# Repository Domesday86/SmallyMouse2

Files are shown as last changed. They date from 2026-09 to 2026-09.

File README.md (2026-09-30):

## Synopsis

SmallyMouse2 is the AT90USB1287 firmware source code and KiCAD schematic/PCB design for the SmallyMouse2 project.

Detailed documentation is available on the [SmallyMouse2 wiki](https://github.com/domesday86/SmallyMouse2/wiki).

The schematic and PCB design in `KiCAD/` are in the KiCad 10 file format and require KiCad 10 or later to open. The original KiCad 4 files are available in the git history (commit `66cf90d` and earlier).

## Motivation

SmallyMouse2 is a project that creates a USB mouse adaptor for retro computers that use quadrature mouse input including the Acorn BBC Micro, Acorn Master series, Commodore Amiga, Atari ST, busmouse compatible computers and many more.  SmallyMouse2 provides both a generic mouse output header (for attaching mouse to retro computer cables) and an IDC connector suitable for use with Acorn 8-bit user-ports.  SmallyMouse2 also features a configurable quadrature rate limiter that prevents VIA overrun when in use with slower 8-bit machines.

SmallyMouse2 supports both JTAG and USB bootloader programming.  The AT90USB1287 is pre-programmed by Atmel with the (FLIP) DFU bootloader; this bootloader is recognised by Atmel Studio as a programming device and can be used to flash the firmware to the board.

## Installation

The firmware is built with the open-source AVR GNU toolchain (avr-gcc, avr-binutils, avr-libc) and CMake. A Nix flake supplies the complete, pinned toolchain along with the programming tools (avrdude for the Atmel-ICE, dfu-programmer for the USB bootloader).

### Building

Enter the firmware development shell (`code`, also the default) and build out-of-tree using a CMake preset:

    nix develop                     # or: nix develop .#code
    cmake --preset release          # or: cmake --preset debug
    cmake --build --preset release

The output is written to `build/release/`:

| File | Use |
|---|---|
| `SmallyMouse2.hex`  | Flash image (Intel HEX) - JTAG via avrdude, DFU via dfu-programmer  |
| `SmallyMouse2-with-bootloader.hex` | Firmware merged with the LUFA DFU bootloader - JTAG via avrdude |
| `SmallyMouse2.elf`  | Full image with symbols - JTAG via Microchip Studio / debugging |
| `SmallyMouse2.eep`  | EEPROM image (currently empty) |
| `SmallyMouse2.srec` | Flash image (Motorola S-record) |
| `SmallyMouse2.lss`  | Extended listing |
| `SmallyMouse2.map`  | Linker map |

Alternatively `nix build` produces the same files in `./result/` without entering a shell.

Without Nix, any avr-gcc toolchain, CMake 3.24+ and Ninja on the `PATH` will work with the same commands.

### Programming via JTAG (Atmel-ICE)

Connect the Atmel-ICE to the JTAG header, then:

    cmake --build --preset release --target flash-jtag

or, without a build tree, `nix run .#flash-jtag`. The fuses and lock bits can be read with the `read-fuses-jtag` target.

Programming over JTAG performs a chip erase, which also removes the DFU bootloader, so `flash-jtag` writes `SmallyMouse2-with-bootloader.hex` (the firmware merged with the LUFA DFU bootloader) and the board can still be updated over USB afterwards. The bootloader image comes from the Nix flake; without it (`BOOTLOADER_HEX` unset) `flash-jtag` writes the firmware alone and the bootloader is lost.

### Restoring the DFU bootloader and fuses (Atmel-ICE)

If the bootloader is missing (for example after programming with another tool) or the fuses no longer select it, connect the Atmel-ICE and run:

    nix run .#flash-bootloader-jtag

or, from the dev shell, `cmake --build --preset release --target flash-bootloader-jtag`. This builds the LUFA DFU bootloader from the pinned LUFA source, erases the chip, writes the bootloader and sets the high/extended fuses to the factory values (`hfuse 0x99`, `efuse 0xF3`: 8 KB boot section, JTAG enabled, HWB bootloader entry enabled). The LUFA bootloader uses the same USB ID as the factory one, so the DFU steps below work unchanged. Any application firmware is removed; reprogram it over USB afterwards.

### Programming via USB (DFU bootloader)

Put the AT90USB1287 into its factory DFU bootloader (hold HWB low while resetting), then:

    cmake --build --preset release --target flash-dfu

or `nix run .#flash-dfu`. The device is erased, programmed and then started.

### USB permissions (udev)

On Linux, programming as a normal user needs udev rules for two devices:

| Device | USB ID | Used by |
|---|---|---|
| Atmel-ICE | `03eb:2141` | avrdude |
| AT90USB1287 DFU bootloader | `03eb:2ffb` | dfu-programmer |

The Atmel-ICE needs two rules. avrdude can reach it through libusb or through hidapi, and each uses a different device node (`usb` and `hidraw`).

On NixOS, add the rules to your system configuration:

```nix
services.udev.extraRules = ''
  # Atmel-ICE (AVR JTAG programmer) - usb node for libusb, hidraw node for hidapi
  SUBSYSTEM=="usb", ATTRS{idVendor}=="03eb", ATTRS{idProduct}=="2141", MODE="660", GROUP="users"
  SUBSYSTEM=="hidraw", ATTRS{idVendor}=="03eb", ATTRS{idProduct}=="2141", MODE="660", GROUP="users"
  # AT90USB1287 DFU bootloader
  SUBSYSTEM=="usb", ATTRS{idVendor}=="03eb", ATTRS{idProduct}=="2ffb", MODE="660", GROUP="users"
'';
```

On other distributions, put the same three lines in a file such as `/etc/udev/rules.d/70-smallymouse2.rules`. Make sure your user is in the group the rules name, or change `GROUP` to one it is in (for example `plugdev` on Debian and Ubuntu). Then reload the rules with `sudo udevadm control --reload-rules`.

On either system, unplug and replug the device after adding the rules.

## Case

`Case/` holds an OpenSCAD case design, built with the [BOSL2](https://github.com/BelfrySCAD/BOSL2) library:

| File | Contents |
|---|---|
| `pcb.scad`  | Dimensional model of the assembled board, built from the footprint placements in `KiCAD/SmallyMouse2.kicad_pcb`, with helpers giving the board-space position of any part by reference (for example `pcb_part_box("P1")` for the USB connector) |
| `case.scad` | Two-part case (base and lid) positioned against the board model |

### Opening the design

From the repository root, enter the `openscad` dev shell and open the case:

    nix develop .#openscad
    openscad Case/case.scad

Start OpenSCAD from inside the dev shell: the shell sets `OPENSCADPATH` to the pinned BOSL2, so `include <BOSL2/std.scad>` fails if OpenSCAD is started any other way (for example from the desktop menu). `openscad Case/pcb.scad` opens the board model on its own.

Open the Customizer (Window → Customizer) and set `part` to choose what is shown:

| `part` | Shows |
|---|---|
| `assembly` | Base, board and a transparent lid together; raise `explode` to lift the lid |
| `base` | The base alone, laid out for printing |
| `lid` | The lid alone, turned over for printing |
| `pcb` | The board alone |

The case dimensions (wall thickness, clearances, standoff height and so on) are in the same panel.

F5 gives a fast preview; F6 does the full render needed before exporting an STL with F7.

### Exporting STLs

Without the GUI, `nix build .#case` renders `case-base.stl`, `case-lid.stl` and `case-pcb.stl` into `./result/`. A single part can be exported from the dev shell with, for example:

    openscad -o case-lid.stl -D 'part="lid"' Case/case.scad

Component heights that are not in the KiCad data (the USB connector, IDC header and pin headers) use typical datasheet values, set near the top of `pcb.scad`; check them against the parts fitted before printing.

## Author

SmallyMouse2 is written and maintained by Simon Inns.

## License (Software)

    SmallyMouse2 is free software: you can redistribute it and/or modify
    it under the terms of the GNU General Public License as published by
    the Free Software Foundation, either version 3 of the License, or
    (at your option) any later version.

    SmallyMouse2 is distributed in the hope that it will be useful,
    but WITHOUT ANY WARRANTY; without even the implied warranty of
    MERCHANTABILITY or FITNESS FOR A PARTICULAR PURPOSE.  See the
    GNU General Public License for more details.

    You should have received a copy of the GNU General Public License
    along with SmallyMouse2. If not, see <http://www.gnu.org/licenses/>.

## License (Hardware)

Both the schematic and the PCB design of SmallyMouse2 (i.e. the KiCAD project and files) are covered by a Creative Commons license; as with the software you are welcome (and encouraged!) to extend, re-spin and otherwise use and modify the design as allowed by the license.  However; under the terms of the Attribution-ShareAlike 4.0 International (CC BY-SA 4.0) license you are required to release your design (or redesign) under the same license.  For details of the licensing requirements please see <https://creativecommons.org/licenses/by-sa/4.0/>

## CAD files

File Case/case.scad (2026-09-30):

// SmallyMouse2 case
//
// A two-part case: a base tray that the board sits in on four standoffs, and
// a lid that closes over it. Both parts split at the top face of the PCB, so
// the USB connector drops into a slot in the lid wall. Four M3 screws go up
// through the base, standoffs and board into pilot holes in the lid pillars,
// clamping everything together.
//
// The case is modelled in the board coordinates of pcb.scad (origin at the
// centre of the board, Z = 0 on its bottom face), so case features can be
// placed directly from the PCB model's measurements. The output is then
// lifted so the base sits on Z = 0, keeping the Z axis through the centre of
// the board.
//
// Set `part` to choose what is rendered; from the command line:
//   openscad -o case-base.stl -D 'part="base"' case.scad

PCB_LIBRARY_ONLY = true;
include <pcb.scad>

part = "assembly";  // [assembly, base, lid, pcb]
explode = 0;        // Lift the lid in the assembly view

/* [Case] */
wall = 2.0;
floor_thickness = 2.0;
top_thickness = 2.0;
corner_radius = 3.0;
board_gap = 0.5;        // Clearance around the board edge
opening_gap = 0.5;      // Clearance around connectors through the lid
usb_gap = 0.3;          // Clearance around the USB shell in the lid slot
usb_protrusion = 0.5;   // USB mouth stands proud of the case wall

/* [Fixings] */
standoff_height = 4.0;  // Must clear PCB_PIN_TAIL
standoff_d = 8.5;       // Must be wider than screw_head_d
pillar_d = 5.5;         // Must fit in PCB_HOLE_KEEPOUT_D
screw_clearance_d = 3.4;
screw_pilot_d = 2.5;    // M3 self-tapping into plastic
screw_head_d = 6.0;
screw_head_depth = 3.0;

/* [Lid openings] */
// J1 expansion header
open_j1 = true;
// J2 slow/fast jumper
open_j2 = true;
// J3 BBC Micro user port (IDC)
open_j3 = true;
// J4 universal output header
open_j4 = true;
// J5 bootloader jumper
open_j5 = true;
// J6 reset jumper
open_j6 = true;
// Gap above a covered connector; the lid is raised to suit
lid_clearance = 1.0;

/* [Hidden] */
// Connectors under the lid, and whether each has an opening
LID_CONNECTORS = [
    ["J1", open_j1],
    ["J2", open_j2],
    ["J3", open_j3],
    ["J4", open_j4],
    ["J5", open_j5],
    ["J6", open_j6],
];
LID_OPENINGS = [for (c = LID_CONNECTORS) if (c[1]) c[0]];
LID_COVERED = [for (c = LID_CONNECTORS) if (!c[1]) c[0]];

// ---------------------------------------------------------------------------
// Derived dimensions (board coordinates)

usb_box = pcb_part_box("P1");

case_min = [usb_box[0].x + usb_protrusion, -PCB_SIZE.y / 2 - board_gap - wall];
case_max = PCB_SIZE / 2 + [board_gap + wall, board_gap + wall];
inner_min = case_min + [wall, wall];
inner_max = case_max - [wall, wall];

z_bottom = -standoff_height - floor_thickness;
z_split = PCB_THICKNESS;
// The lid underside clears the USB shell and any covered connector; the IDC
// shroud, when it has an opening, reaches the lid's top
z_top = max([
    pcb_part_top("P1") + usb_gap + top_thickness,
    if (open_j3) pcb_part_top("J3"),
    for (ref = LID_COVERED) pcb_part_top(ref) + lid_clearance + top_thickness,
]);
z_ceiling = z_top - top_thickness;

assert(standoff_height > PCB_PIN_TAIL, "Standoffs too short for the pin tails");
assert(standoff_d >= screw_head_d + 2, "Standoffs too thin around the screw head recess");
assert(pillar_d <= PCB_HOLE_KEEPOUT_D, "Lid pillars overlap the hole keep-out");

echo(str("Case outside: ", case_max - case_min, " x ", z_top - z_bottom, " mm"));
echo(str("Screw: M3 x ", floor(z_ceiling - z_bottom - screw_head_depth - 1), " mm or shorter"));

// ---------------------------------------------------------------------------

// Rounded box between two XY corners, from z0 to z1.
module rounded_box(p0, p1, z0, z1, r) {
    translate([(p0.x + p1.x) / 2, (p0.y + p1.y) / 2, z0])
        cuboid([p1.x - p0.x, p1.y - p0.y, z1 - z0], rounding = r, edges = "Z",
               anchor = BOT);
}

module shell(z0, z1) {
    difference() {
        rounded_box(case_min, case_max, z0, z1, corner_radius);
        rounded_box(inner_min, inner_max, z0 - 1, z1 + 1, corner_radius - wall);
    }
}

module base() {
    difference() {
        union() {
            shell(z_bottom, z_split);
            rounded_box(case_min, case_max, z_bottom, z_bottom + floor_thickness,
                        corner_radius);
            for (h = PCB_HOLES) translate(h)
                cyl(d = standoff_d, h = standoff_height, anchor = TOP);
        }
        for (h = PCB_HOLES) translate(h) {
            cyl(d = screw_clearance_d, h = 50);
            translate([0, 0, z_bottom - 1])
                cyl(d = screw_head_d, h = screw_head_depth + 1, anchor = BOT);
        }
    }
}

// Screw pillars from the lid's underside down to the top of the board.
module lid_pillars() {
    for (h = PCB_HOLES) translate([h.x, h.y, PCB_THICKNESS])
        cyl(d = pillar_d, h = z_ceiling - PCB_THICKNESS, anchor = BOT);
}

// Blind pilot holes for the screws
module lid_pilot_holes() {
    for (h = PCB_HOLES) translate([h.x, h.y, PCB_THICKNESS - 1])
        cyl(d = screw_pilot_d, h = z_top - PCB_THICKNESS, anchor = BOT);
}

module lid() {
    difference() {
        union() {
            shell(z_split, z_top);
            rounded_box(case_min, case_max, z_ceiling, z_top, corner_radius);
            lid_pillars();
        }
        lid_pilot_holes();
        // USB slot, open at the bottom of the lid wall
        translate([0, 0, z_split - 1])
            cube_between([case_min.x - 1, usb_box[0].y - usb_gap],
                         [inner_min.x + 1, usb_box[1].y + usb_gap],
                         pcb_part_top("P1") + usb_gap - z_split + 1);
        for (ref = LID_OPENINGS) let (b = pcb_part_box(ref))
            translate([0, 0, z_ceiling - 1])
                cube_between(b[0] - [opening_gap, opening_gap],
                             b[1] + [opening_gap, opening_gap], top_thickness + 2);
    }
}

// Square-edged block between two XY corners, from z = 0 to z = h.
module cube_between(p0, p1, h) {
    translate([p0.x, p0.y, 0]) cube([p1.x - p0.x, p1.y - p0.y, h]);
}

// Lifts from board coordinates to the output frame, with the underside of
// the base on Z = 0.
module on_bed() {
    translate([0, 0, -z_bottom]) children();
}

if (part == "assembly") {
    on_bed() {
        color("#606060") base();
        smallymouse2_pcb();
        translate([0, 0, explode]) {
            // The preview (F5) hides whatever is drawn after a transparent
            // part, including the lid's own pillars, so they are drawn again
            // as solid parts before the lid
            if ($preview) color("SteelBlue") difference() {
                lid_pillars();
                lid_pilot_holes();
            }
            color("SteelBlue", 0.5) lid();
        }
    }
} else if (part == "base") {
    on_bed() base();
} else if (part == "lid") {
    // Top down on the print bed
    translate([0, 0, z_top - z_bottom]) xrot(180) on_bed() lid();
} else if (part == "pcb") {
    // Where it sits in the assembly, so it lines up with the base
    on_bed() smallymouse2_pcb();
}

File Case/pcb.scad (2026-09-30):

// SmallyMouse2 PCB model for case design
//
// A dimensional model of the assembled SmallyMouse2 board, built from the
// footprint placements in KiCAD/SmallyMouse2.kicad_pcb. It is meant for
// measuring a case against, not as a photorealistic render: component bodies
// are simple blocks at their nominal (datasheet-typical) sizes.
//
// Board coordinates (used by everything in this file and by case.scad):
//   origin  - centre of the board outline, on the bottom face of the PCB
//   X       - right, along the 52.3 mm edge
//   Y       - up the board, as seen in KiCad's top view
//   Z       - up from the bottom face; the top (component) face is at
//             PCB_THICKNESS
//
// Footprints are described in their own KiCad-local coordinates (Y down),
// so the numbers below can be checked directly against the .kicad_pcb and
// the footprints in KiCAD/SmallyMouse2.pretty.
//
// Open this file on its own to view the board. case.scad includes it as a
// library by setting PCB_LIBRARY_ONLY first.

include <BOSL2/std.scad>

$fa = 4;
$fs = 0.25;

// ---------------------------------------------------------------------------
// Board

// Edge.Cuts rectangle: (120.904, 80.264) - (173.228, 122.428) in KiCad
PCB_KICAD_ORIGIN = [147.066, 101.346];  // KiCad position of the board centre
PCB_SIZE = [52.324, 42.164];
PCB_THICKNESS = 1.6;

// M3 mounting holes (MK1-MK4). The keep-out is the ISO 14580 screw head
// courtyard on the top side.
PCB_HOLE_D = 3.2;
PCB_HOLE_KEEPOUT_D = 6.0;

// Through-hole pins stand proud of the bottom face by this much (2.54 mm
// headers: 3.0 mm tail below the plastic, less the board thickness). Leave at
// least this under the board.
PCB_PIN_TAIL = 3.0 - PCB_THICKNESS;

// ---------------------------------------------------------------------------
// Component sizes that are not in the KiCad data. These come from typical
// datasheet values; check against the parts actually fitted.

USB_A_HEIGHT = 7.0;         // Amphenol 87583-2010BLF shell height above board
IDC_HEIGHT = 8.9;           // 2x10 boxed (shrouded) header
HEADER_BODY_HEIGHT = 2.5;   // 2.54 mm pin header plastic
HEADER_PIN_HEIGHT = 8.5;    // 2.54 mm pin header, pin tip above board
TQFP_HEIGHT = 1.2;
XTAL_HEIGHT = 1.2;
C0805_HEIGHT = 0.85;
R0805_HEIGHT = 0.5;

// ---------------------------------------------------------------------------
// Footprint placements, from the .kicad_pcb:
//   [reference, type, KiCad position, KiCad rotation, pin count]

PCB_PARTS = [
    ["C1",  "C0805",  [132.334, 109.474],  90],
    ["C2",  "C0805",  [135.128, 109.474],  90],
    ["C3",  "C0805",  [141.478,  89.662], 180],
    ["C4",  "C0805",  [135.128, 100.076],  90],
    ["C5",  "C0805",  [136.652,  89.662], 180],
    ["C6",  "C0805",  [141.224, 110.998], 180],
    ["C7",  "C0805",  [149.352,  89.408],   0],
    ["C8",  "C0805",  [151.892, 115.062],   0],
    ["C9",  "C0805",  [163.830, 119.888], 180],
    ["C10", "C0805",  [161.290,  83.058],   0],
    ["R1",  "R0805",  [133.350,  96.774], 180],
    ["R2",  "R0805",  [133.350,  94.742], 180],
    ["R3",  "R0805",  [153.924, 111.252], -90],
    ["R4",  "R0805",  [126.365,  89.408], -90],
    ["IC1", "TQFP64", [145.288, 100.076],   0],
    ["Y1",  "XTAL",   [134.874, 114.046], 180],
    ["P1",  "USB_A",  [126.492, 101.346], -90],
    ["J1",  "HEADER", [130.302, 118.872],  90, 10],  // Expansion header
    ["J2",  "HEADER", [153.162,  86.614], 180,  2],  // Slow/Fast jumper
    ["J3",  "IDC20",  [162.306, 113.030],  90],      // BBC Micro user port
    ["J4",  "HEADER", [168.656, 113.030], 180, 10],  // Universal output
    ["J5",  "HEADER", [131.826, 104.648],  90,  2],  // Bootloader jumper
    ["J6",  "HEADER", [129.413,  90.170], 180,  2],  // Reset jumper
    ["TP1", "TP",     [132.080,  83.820],   0],      // JTAG test points
    ["TP2", "TP",     [137.668,  83.820],   0],
    ["TP3", "TP",     [143.256,  83.820],   0],
    ["TP4", "TP",     [146.050,  83.820], 180],
    ["TP5", "TP",     [134.874,  83.820], 180],
    ["TP6", "TP",     [140.462,  83.820], 180],
    ["TP7", "TP",     [148.844,  83.820],   0],
];

PCB_MOUNTING_HOLES_KICAD = [
    [124.460,  83.820],  // MK1
    [124.460, 118.618],  // MK2
    [169.672,  83.820],  // MK3
    [169.672, 118.618],  // MK4
];

// ---------------------------------------------------------------------------
// Coordinate conversion

// KiCad board position -> board coordinates
function kicad_xy(p) = [p.x - PCB_KICAD_ORIGIN.x, PCB_KICAD_ORIGIN.y - p.y];

// Footprint-local point -> board coordinates. KiCad's local Y points down and
// its rotation is counter-clockwise as seen from the top, so flipping Y turns
// it into an ordinary OpenSCAD rotation.
function fp_xy(at, rot, p) =
    let (c = cos(rot), s = sin(rot), q = [p.x, -p.y])
    kicad_xy(at) + [c * q.x - s * q.y, s * q.x + c * q.y];

// Places children, modelled in footprint-local coordinates with Z = 0 on the
// board's top face, onto the board.
module footprint(at, rot) {
    translate([each kicad_xy(at), PCB_THICKNESS]) zrot(rot) yflip() children();
}

PCB_HOLES = [for (h = PCB_MOUNTING_HOLES_KICAD) kicad_xy(h)];

// ---------------------------------------------------------------------------
// Part lookup, for positioning case features

function pcb_part(ref) = [for (p = PCB_PARTS) if (p[0] == ref) p][0];

// Local-coordinate outline [[x0, y0], [x1, y1]] and height above the board
// of each footprint type.
function part_outline(part) =
    let (type = part[1], pins = part[4])
      type == "C0805"  ? [[-1.0, -0.625], [1.0, 0.625]]
    : type == "R0805"  ? [[-1.0, -0.625], [1.0, 0.625]]
    : type == "TQFP64" ? [[-8, -8], [8, 8]]
    : type == "XTAL"   ? [[-2.5, -1.6], [2.5, 1.6]]
    : type == "USB_A"  ? [[-6.57, -1.07], [6.57, 12.84]]
    : type == "IDC20"  ? [[-5.08, -5.82], [27.94, 3.28]]
    : type == "HEADER" ? [[-1.27, -1.27], [1.27, (pins - 0.5) * 2.54]]
    : type == "TP"     ? [[-0.75, -0.75], [0.75, 0.75]]
    : assert(false, str("Unknown footprint type ", type));

function part_height(part) =
    let (type = part[1])
      type == "C0805"  ? C0805_HEIGHT
    : type == "R0805"  ? R0805_HEIGHT
    : type == "TQFP64" ? TQFP_HEIGHT
    : type == "XTAL"   ? XTAL_HEIGHT
    : type == "USB_A"  ? USB_A_HEIGHT
    : type == "IDC20"  ? IDC_HEIGHT
    : type == "HEADER" ? HEADER_PIN_HEIGHT
    : type == "TP"     ? 0.05
    : assert(false, str("Unknown footprint type ", type));

// Board-coordinate bounding box [[x0, y0], [x1, y1]] of a part, e.g.
// pcb_part_box("P1") for the USB connector (its mouth is the -X face).
function pcb_part_box(ref) =
    let (
        part = pcb_part(ref),
        o = part_outline(part),
        pts = [for (x = [o[0].x, o[1].x], y = [o[0].y, o[1].y])
                   fp_xy(part[2], part[3], [x, y])]
    )
    [[min([for (p = pts) p.x]), min([for (p = pts) p.y])],
     [max([for (p = pts) p.x]), max([for (p = pts) p.y])]];

// Height of a part's top above the bottom face of the board.
function pcb_part_top(ref) = PCB_THICKNESS + part_height(pcb_part(ref));

// Tallest part, above the bottom face of the board.
PCB_TOP = max([for (p = PCB_PARTS) PCB_THICKNESS + part_height(p)]);

// ---------------------------------------------------------------------------
// Model

PCB_COLOUR = "#1f6b2d";
COPPER_COLOUR = "gold";
METAL_COLOUR = "silver";
PLASTIC_COLOUR = "#202020";

// Box between two local-coordinate corners, from z0 to z1.
module _box(p0, p1, z0, z1) {
    translate([(p0.x + p1.x) / 2, (p0.y + p1.y) / 2, z0])
        cuboid([abs(p1.x - p0.x), abs(p1.y - p0.y), z1 - z0], anchor = BOT);
}

module _chip(height, body_colour) {
    color(body_colour) _box([-0.75, -0.625], [0.75, 0.625], 0, height);
    color(METAL_COLOUR)
        for (x = [-1, 1]) _box([x * 0.75, -0.625], [x * 1.0, 0.625], 0, height);
}

module _tqfp64() {
    color(PLASTIC_COLOUR) difference() {
        _box([-7, -7], [7, 7], 0.1, TQFP_HEIGHT);
        // Pin 1 marker
        translate([-5.5, -5.5, TQFP_HEIGHT]) cyl(d = 1, h = 0.2);
    }
    color(METAL_COLOUR)
        for (side = [0 : 3], i = [0 : 15])
            zrot(side * 90) translate([7.5, (i - 7.5) * 0.8, 0])
                cuboid([1, 0.37, 0.15], anchor = BOT);
}

module _xtal() {
    color("#c8b88a") _box([-2.5, -1.6], [2.5, 1.6], 0, 0.3);
    color(METAL_COLOUR) _box([-2.3, -1.4], [2.3, 1.4], 0.3, XTAL_HEIGHT);
}

// Amphenol 87583-2010BLF USB-A receptacle; the mouth faces local +Y.
module _usb_a() {
    color(METAL_COLOUR) difference() {
        _box([-6.57, -1.07], [6.57, 12.84], 0, USB_A_HEIGHT);
        _box([-6.0, 2.84], [6.0, 12.94], 1.0, USB_A_HEIGHT - 1.0);
    }
    color("white") _box([-5.6, 2.84], [5.6, 11.84], 3.4, 5.2);
    // Board-locating shell pegs through the 2.3 mm holes
    color(METAL_COLOUR)
        for (x = [-6.57, 6.57]) translate([x, 2.14, 0])
            cyl(d = 2.0, h = PCB_THICKNESS + 1, anchor = TOP);
    color(METAL_COLOUR)
        for (x = [-3.5, -1, 1, 3.5]) _box([x - 0.3, -2.5], [x + 0.3, -1.07], 0, 0.2);
}
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

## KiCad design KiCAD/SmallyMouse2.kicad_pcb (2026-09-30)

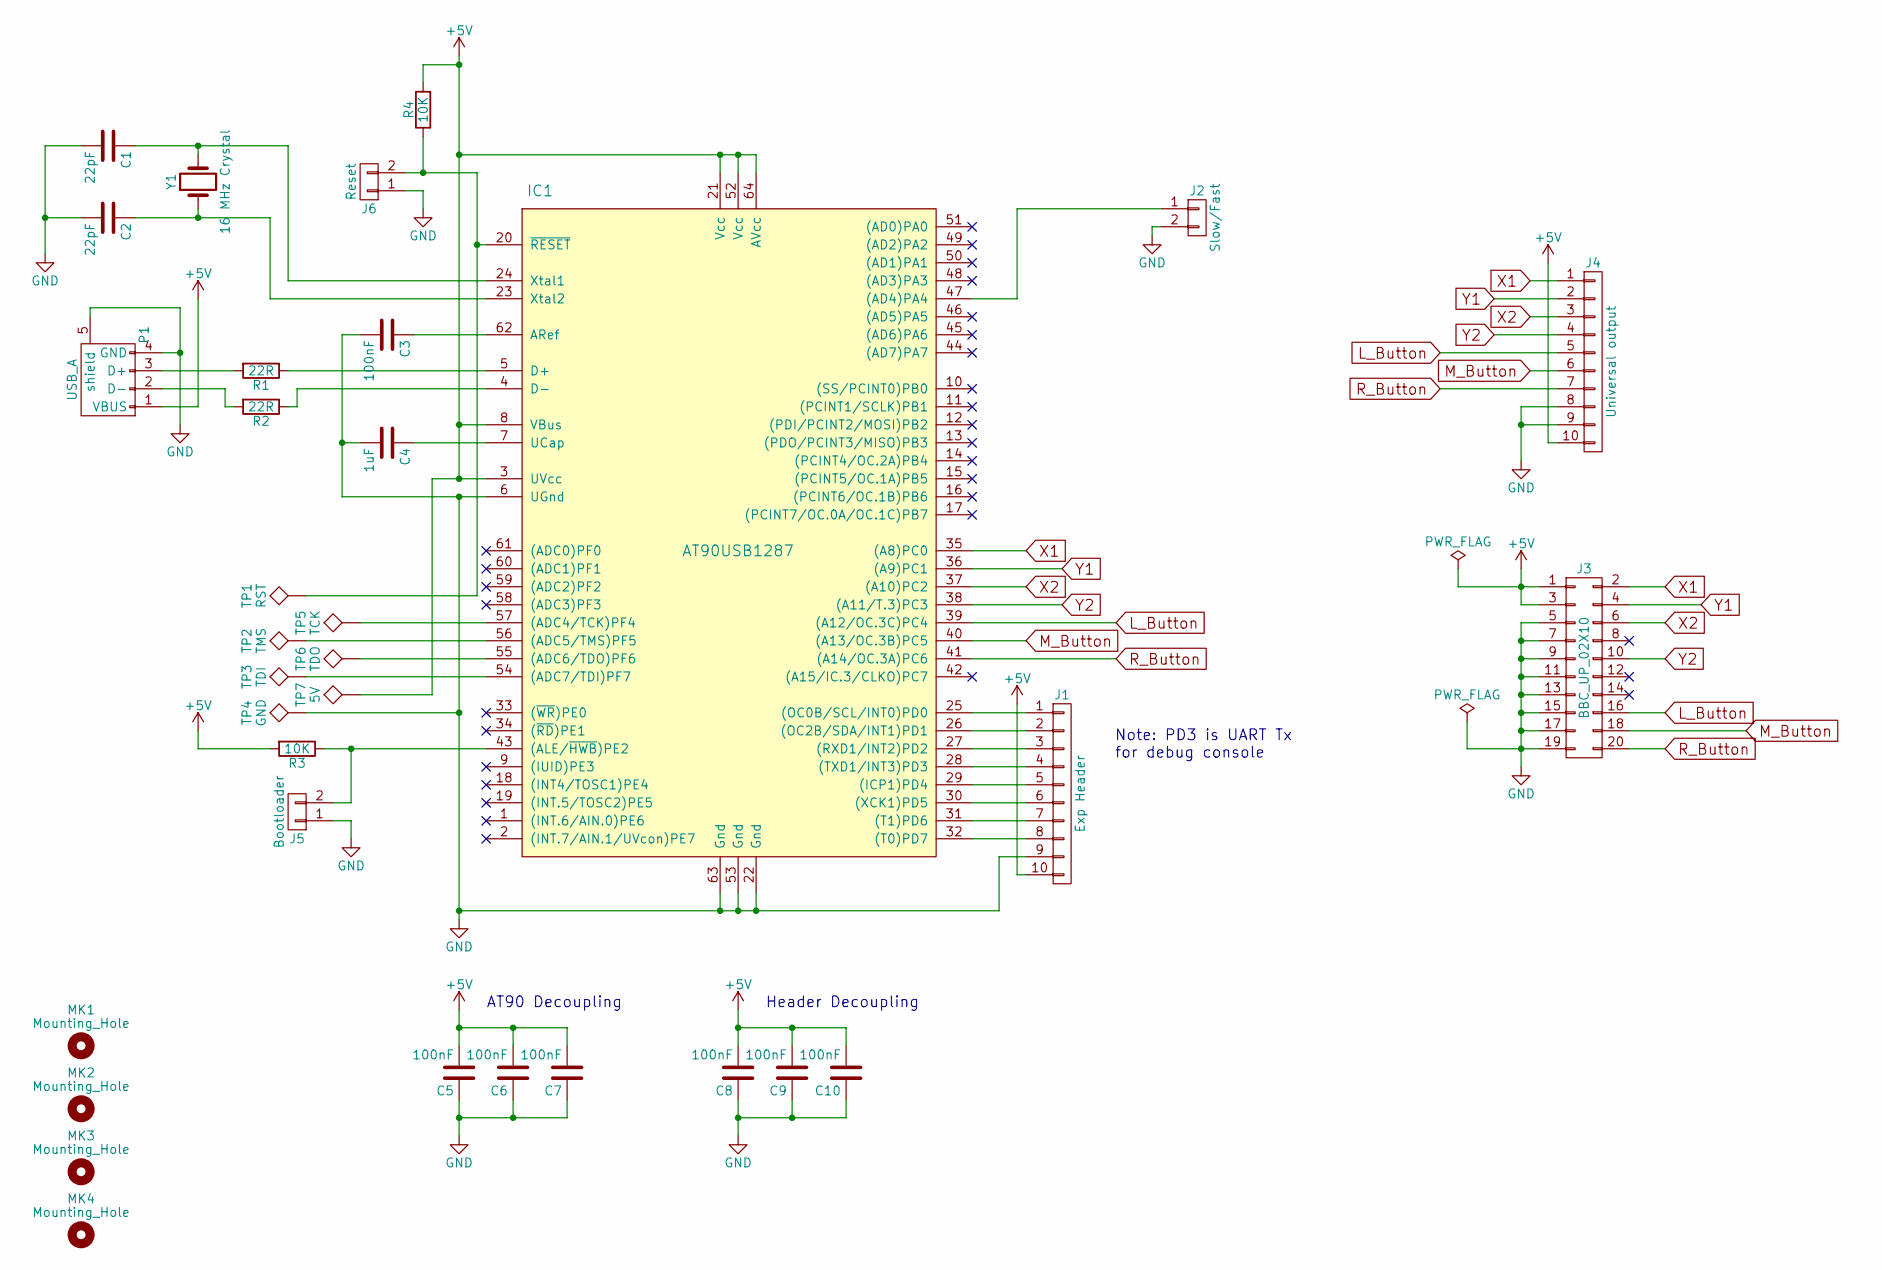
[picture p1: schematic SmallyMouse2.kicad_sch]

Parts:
C1, C2: 22pF; C_0805_HandSoldering
C3, C5, C6, C7, C8, C9, C10: 100nF; C_0805_HandSoldering
C4: 1uF; C_0805_HandSoldering
IC1: AT90USB1287; TQFP-64_14x14mm_Pitch0.8mm
J1: Exp Header; Pin_Header_Straight_1x10_Pitch2.54mm
J2: Slow/Fast; Pin_Header_Straight_1x02_Pitch2.54mm
J3: BBC_UP_02X10; IDC_Header_Straight_20pins
J4: Universal output; Pin_Header_Straight_1x10_Pitch2.54mm
J5: Bootloader; Pin_Header_Straight_1x02_Pitch2.54mm
J6: Reset; Pin_Header_Straight_1x02_Pitch2.54mm
MK1, MK2, MK3, MK4: Mounting_Hole; MountingHole_3.2mm_M3_ISO14580
P1: USB_A; Amphenol_87583-2010BLF
R1, R2: 22R; R_0805_HandSoldering
R3, R4: 10K; R_0805_HandSoldering
TP1: RST; Measurement_Point_Square-SMD-Pad_Small
TP2: TMS; Measurement_Point_Square-SMD-Pad_Small
TP3: TDI; Measurement_Point_Square-SMD-Pad_Small
TP4: GND; Measurement_Point_Square-SMD-Pad_Small
TP5: TCK; Measurement_Point_Square-SMD-Pad_Small
TP6: TDO; Measurement_Point_Square-SMD-Pad_Small
TP7: 5V; Measurement_Point_Square-SMD-Pad_Small
Y1: 16 MHz Crystal; Crystal_SMD_5032-2pin_5.0x3.2mm_HandSoldering

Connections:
+5V: C5.2, C6.2, C7.2, C8.2, C9.2, C10.2, IC1.3 (UVcc), IC1.8 (VBus), IC1.21 (Vcc), IC1.52 (Vcc), IC1.64 (AVcc), J1.10, J3.1, J3.3, J4.10, P1.1 (VBUS), R3.2, R4.2, TP7.1 (~_1)
GND: C1.2, C2.2, C3.2, C4.2, C5.1, C6.1, C7.1, C8.1, C9.1, C10.1, IC1.6 (UGnd), IC1.22 (Gnd), IC1.53 (Gnd), IC1.63 (Gnd), J1.9, J2.2, J3.5, J3.7, J3.9, J3.11, J3.13, J3.15, J3.17, J3.19, J4.8, J4.9, J5.1, J6.1, P1.4 (GND), P1.5 (shield), TP4.1 (~_1)
L_Button: IC1.39 ((A12/OC.3C)PC4), J3.16, J4.5
M_Button: IC1.40 ((A13/OC.3B)PC5), J3.18, J4.6
unnamed: IC1.47 ((AD4)PA4), J2.1
unnamed: IC1.57 ((ADC4/TCK)PF4), TP5.1 (~_1)
unnamed: IC1.56 ((ADC5/TMS)PF5), TP2.1 (~_1)
unnamed: IC1.55 ((ADC6/TDO)PF6), TP6.1 (~_1)
unnamed: IC1.54 ((ADC7/TDI)PF7), TP3.1 (~_1)
unnamed: IC1.43 ((ALE/~HWB)PE2), J5.2, R3.1
unnamed: IC1.29 ((ICP1)PD4), J1.5
unnamed: IC1.25 ((OC0B/SCL/INT0)PD0), J1.1
unnamed: IC1.26 ((OC2B/SDA/INT1)PD1), J1.2
unnamed: IC1.27 ((RXD1/INT2)PD2), J1.3
unnamed: IC1.32 ((T0)PD7), J1.8
unnamed: IC1.31 ((T1)PD6), J1.7
unnamed: IC1.28 ((TXD1/INT3)PD3), J1.4
unnamed: IC1.30 ((XCK1)PD5), J1.6
unnamed: C3.1, IC1.62 (ARef)
unnamed: IC1.5 (D+), R1.1
unnamed: IC1.4 (D-), R2.1
unnamed: C4.1, IC1.7 (UCap)
unnamed: C1.1, IC1.24 (Xtal1), Y1.2
unnamed: C2.1, IC1.23 (Xtal2), Y1.1
unnamed: IC1.20 (~RESET), J6.2, R4.1, TP1.1 (~_1)
unnamed: P1.3 (D+), R1.2
unnamed: P1.2 (D-), R2.2
R_Button: IC1.41 ((A14/OC.3A)PC6), J3.20, J4.7
X1: IC1.35 ((A8)PC0), J3.2, J4.1
X2: IC1.37 ((A10)PC2), J3.6, J4.3
Y1: IC1.36 ((A9)PC1), J3.4, J4.2
Y2: IC1.38 ((A11/T.3)PC3), J3.10, J4.4

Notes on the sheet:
AT90 Decoupling
Note: PD3 is UART Tx for debug console
Header Decoupling

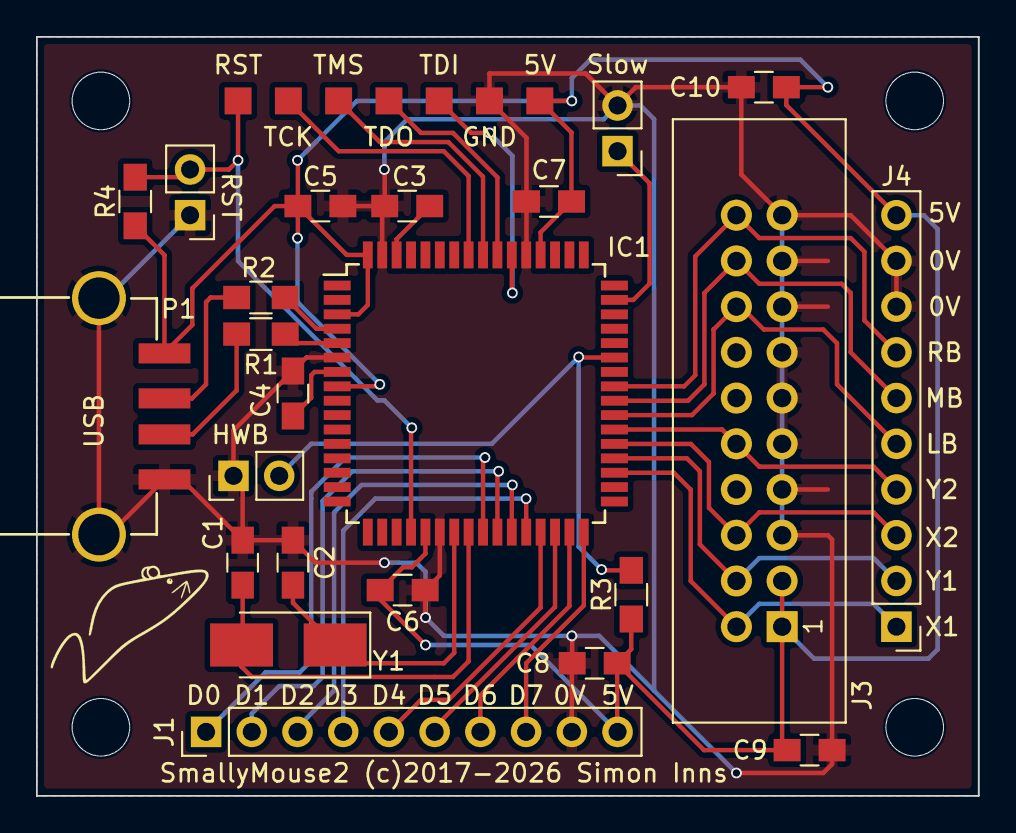
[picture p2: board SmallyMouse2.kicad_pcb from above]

Board: 2 copper layers, 52.3 x 42.2 mm, 34 parts (0 on the bottom side), 32 nets.

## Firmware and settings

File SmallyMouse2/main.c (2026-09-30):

/*
 * SPDX-License-Identifier: GPL-3.0-or-later
 * SPDX-FileCopyrightText: 2017-2026 Simon Inns <simon.inns@gmail.com>
 *
 * main.c - Main functions
 * SmallyMouse2 - USB to quadrature mouse converter
 */

// Important notice:  If you port this firmware to another hardware design
// it *will be* a derivative of the original and therefore you must pay attention
// to the CC hardware licensing and release your hardware design as per the share-
// alike license.  Keep it open! ...and yes, that includes you Commodore chaps.

// System includes
#include <avr/io.h>
#include <avr/wdt.h>
#include <avr/pgmspace.h>
#include <avr/interrupt.h>
#include <avr/power.h>
#include <stdio.h>
#include <stdlib.h>
#include <string.h>

#include <util/delay.h>
#include <util/atomic.h>

// Note: SmallyMouse2 makes extensive use of the LUFA libraries:
//
// LUFA Library
// Copyright (C) Dean Camera, 2015.
// dean [at] fourwalledcubicle [dot] com
// www.lufa-lib.org

// Include LUFA libraries
#include <LUFA/Drivers/Misc/TerminalCodes.h>
#include <LUFA/Drivers/USB/USB.h>
#include <LUFA/Drivers/Peripheral/Serial.h>
#include <LUFA/Platform/Platform.h>

#include "ConfigDescriptor.h"
#include "serial.h"
#include "main.h"

#define MOUSEX	0
#define MOUSEY	1

// USB mouse report button bits used for the quadrature mouse buttons
#define BUTTON_LEFT		0x01
#define BUTTON_RIGHT	0x02
#define BUTTON_MIDDLE	0x04

// Button mapping exceptions
//
// Some USB mice report their buttons on unexpected report bits (for example a trackball
// where the two buttons reported as left and right are both on the same side of the ball).
// Mice listed here (identified by their USB VID:PID) have their report button bits remapped
// before they are output.
//
// buttonMap gives, for each report bit (0-7), the report bit it is output as.  The quadrature
// mouse buttons are output from bit 0 (left), bit 1 (right) and bit 2 (middle).  More than one
// report bit can be mapped to the same output bit.  An unlisted mouse uses the report bits
// as they are.
//
// The debug console shows the VID:PID when a mouse is attached and the report bits of any
// pressed buttons.
typedef struct {
	uint16_t vendorId;
	uint16_t productId;
	uint8_t buttonMap[8];
} ButtonMapping_t;

// The following button mapping exceptions are only for the wired and wireless Kensington expert mice.
// The reason is Domesday AIV systems RB2 trackballs have a odd layout and these devices are used as
// replacements.  Remapping is based on VID:PID, so other mice will be unaffected.
static const ButtonMapping_t buttonMappings[] PROGMEM = {
	// Kensington Expert Mouse: bit 0 is output as right, bits 1 and 2 as left and bit 3 as middle
	{ 0x047D, 0x1020, { 1, 0, 0, 2, 4, 5, 6, 7 } },
	// Kensington Expert Mouse Wireless: as the wired version
	{ 0x047D, 0x8018, { 1, 0, 0, 2, 4, 5, 6, 7 } },
};

// Button mapping for the attached mouse (set on enumeration)
uint8_t buttonMap[8] = { 0, 1, 2, 3, 4, 5, 6, 7 };

// Configuration ------------------------------------------------------------------------------------------------------

// Quadrature output frequency limit
//
// This setting limits the maximum frequency of the quadrature output towards the retro computer.
// If the rate of output is too high the retro computer cannot 'count' the input accurately and
// this causes spurious mouse movement.
//
// All quadrature frequencies are given in Hz of full quadrature cycles.  Each cycle is 4 edges
// (phase changes) and each USB movement unit is output as one edge.
//
// Q_MAXRATE is the maximum output frequency with no rate limit (this also limits how often the
// output ISRs are called, so it should not be raised much).
//
// For 8-bit machines it is recommended that the speed doesn't exceed 1000 Hz.  Q_RATELIMIT is
// only applied if the 'slow' configuration jumper is shorted (i.e. on)
//
// On the Acorn 8-bit user port one quadrature line per axis drives a 6522 VIA
// interrupt input (CB1 for X, CB2 for Y) and the other line is read from port B by the
// interrupt handler to get the direction.  The VIA detects the edge in under 1 uS (so the
// VIA itself is not the limit) but the direction line changes one edge after the interrupt
// edge, so the 6502 must reach the handler and read port B within one edge period
// (1 / (4 * Q_RATELIMIT)).  If it doesn't, the direction is misread and the movement stalls
// or reverses.  1000 Hz gives 250 uS, several times the typical MOS interrupt latency.
//
// The VIA interrupts once per quadrature cycle for each axis, so the rate also sets the load
// on the retro computer's CPU when the mouse moves quickly (2 * Q_RATELIMIT interrupts per
// second with both axes moving).  Higher rates leave less time for the running program.
//
// The output is never faster than the configured frequency (the timer period is rounded up)
#define Q_MAXRATE 3906
#ifndef Q_RATELIMIT
#define Q_RATELIMIT 1000
#endif

// Quadrature output drain time
//
// Buffered movement is output over this period (in uS).  10,000 uS matches the report
// interval of a USB mouse reporting at 100 Hz.  If the reports arrive faster than this
// the buffer grows until the output rate matches the input rate (i.e. the output lags
// the USB mouse by about this time).
#define Q_DRAINTIME 10000

// Quadrature output buffer limit
//
// Since the slow rate limit will prevent the quadrature output keeping up with the USB movement
// report input, the quadrature output will lag behind (i.e. the quadrature mouse will continue
// to move after the USB mouse has stopped).  This setting limits the maximum number of buffered
// movements to the quadrature output.  If the buffer reaches this value further USB movements
// will be discarded
//
// When the rate limit is on the buffer is limited to the movement that can be output at
// Q_RATELIMIT in Q_DRAINTIME instead (see Q_RATELIMIT_BUFFERLIMIT), so the quadrature mouse
// lags the USB mouse by no more than Q_DRAINTIME.  Movement faster than the rate limit is
// discarded rather than output late.
#define Q_BUFFERLIMIT 300

// DPI Divider
//
// Some USB mice have very high DPI which causes the quadrature rate to be too high (making the
// mouse move too fast).  If the DPISW header is shorted the following constant will be used to 
// divide the DPI rate to slow things down.  2 or 3 are reasonable values.
#define DPI_DIVIDER 2

// Button debug output
//
// Uncomment the following to show the USB mouse report button state on the debug console
// whenever it changes (each pressed button's report bit and the quadrature mouse button it
// is output as).  This is useful for working out the button mapping exception for a mouse.
//#define DEBUG_BUTTONS

// Quadrature output timer ---------------------------------------------------------------------------------------------

// Timer1 (X) and Timer3 (Y) are 16-bit timers clocked at F_CPU / 8 (0.5 uS per tick at 16 MHz).
// Q_TIMER_PRESCALE must match the CSn1 prescale setting in initialiseTimers()
#define Q_TIMER_PRESCALE 8UL
#define Q_TICKS_PER_SECOND (F_CPU / Q_TIMER_PRESCALE)

// Convert a quadrature frequency (in Hz of full cycles) into timer ticks per edge (rounded up)
#define Q_HZ_TO_TICKS(hz) ((Q_TICKS_PER_SECOND + (4UL * (hz)) - 1) / (4UL * (hz)))

// Timer ticks per edge at the maximum and rate limited output frequencies
#define Q_MAXRATE_TICKS Q_HZ_TO_TICKS(Q_MAXRATE)
#define Q_RATELIMIT_TICKS Q_HZ_TO_TICKS(Q_RATELIMIT)

// Timer ticks to drain the buffer over (split to avoid overflowing 32-bit arithmetic)
#define Q_DRAINTIME_TICKS (((Q_TICKS_PER_SECOND / 1000UL) * Q_DRAINTIME) / 1000UL)

// Range check the configuration at compile time.  Timer periods must fit into the 16-bit
// timer (TOP = ticks - 1 must be 0-65535), the mouse distance (int16_t) must not overflow
// when a report is added before the buffer limit is applied, and the DPI remainder (int8_t)
// must hold +/-(DPI_DIVIDER - 1)
#if (F_CPU % (Q_TIMER_PRESCALE * 1000UL)) != 0
#error "F_CPU / Q_TIMER_PRESCALE must be a whole number of ticks per mS"
#endif
#if (Q_MAXRATE < 1) || (Q_MAXRATE_TICKS > 65536)
#error "Q_MAXRATE is out of range"
#endif
#if (Q_RATELIMIT < 1) || (Q_RATELIMIT_TICKS > 65536)
#error "Q_RATELIMIT is out of range"
#endif
#if (Q_DRAINTIME_TICKS < 1) || (Q_DRAINTIME_TICKS > 65535)
#error "Q_DRAINTIME is out of range"
#endif
#if (Q_BUFFERLIMIT < 1) || (Q_BUFFERLIMIT > (32767 - 128))
#error "Q_BUFFERLIMIT is out of range"
#endif
#if (DPI_DIVIDER < 1) || (DPI_DIVIDER > 128)
#error "DPI_DIVIDER is out of range"
#endif

// Quadrature output buffer limit when the rate limit is on: the number of edges output at
// Q_RATELIMIT in Q_DRAINTIME (40 at 1000 Hz), at least 1 and no more than Q_BUFFERLIMIT
#define Q_RATELIMIT_DRAINUNITS (Q_DRAINTIME_TICKS / Q_RATELIMIT_TICKS)
#if Q_RATELIMIT_DRAINUNITS < 1
#define Q_RATELIMIT_BUFFERLIMIT 1
#elif Q_RATELIMIT_DRAINUNITS > Q_BUFFERLIMIT
#define Q_RATELIMIT_BUFFERLIMIT Q_BUFFERLIMIT
#else
#define Q_RATELIMIT_BUFFERLIMIT Q_RATELIMIT_DRAINUNITS
#endif

#ifdef DEBUG_BUTTONS
// Last USB mouse report button state (used to report button changes on the debug console)
uint8_t previousButtons = 0;
#endif

// Interrupt Service Routines for quadrature output -------------------------------------------------------------------

// The following globals are used by the interrupt service routines to track the mouse
// movement.  The mouseDirection indicates which direction the mouse is moving in and
// the mouseEncoderPhase tracks the current phase of the quadrature output.
//
// The mouseDistance variable tracks the current distance the mouse has left to move
// (this is incremented by the USB mouse reports and decremented by the ISRs as they
// output the quadrature to the retro host).
//
// The mouseDistance variables are 16-bit and shared with the ISRs, so any access from
// outside the ISRs must be made inside an ATOMIC_BLOCK.
//
// The output pins are derived from the phase as a fixed Gray code (for X; Y has the
// pins swapped):
//
//   Phase:  0  1  2  3
//   X1:     1  1  0  0
//   X2:     0  1  1  0
//
// The phase starts at 3 to match the initial pin state of X1 = 0, X2 = 0.
//
// Each ISR disables its own interrupt when there is no distance left to move (so the
// ISRs do not run while the mouse is idle).  processMouse() restarts it when there is
// new movement to output (see startQuadratureTimers()).
volatile int8_t mouseDirectionX = 0;		// X direction (0 = decrement, 1 = increment)
volatile int8_t mouseEncoderPhaseX = 3;		// X Quadrature phase (0-3)

volatile int8_t mouseDirectionY = 0;		// Y direction (0 = decrement, 1 = increment)
volatile int8_t mouseEncoderPhaseY = 3;		// Y Quadrature phase (0-3)

volatile int16_t mouseDistanceX = 0;		// Distance left for mouse to move
volatile int16_t mouseDistanceY = 0;		// Distance left for mouse to move

volatile uint16_t xTimerTop = Q_MAXRATE_TICKS - 1;	// X axis timer TOP value (16-bit, use an ATOMIC_BLOCK outside the ISRs)
volatile uint16_t yTimerTop = Q_MAXRATE_TICKS - 1;	// Y axis timer TOP value (16-bit, use an ATOMIC_BLOCK outside the ISRs)

// Interrupt Service Routine based on Timer1 for mouse X movement quadrature output
ISR(TIMER1_COMPA_vect)
{
	// Process X output
	if (mouseDistanceX > 0) {
		// Change phase and range check
		if (mouseDirectionX == 0) {
			mouseEncoderPhaseX--;
			if (mouseEncoderPhaseX < 0) mouseEncoderPhaseX = 3;
			} else {
			mouseEncoderPhaseX++;
			if (mouseEncoderPhaseX > 3) mouseEncoderPhaseX = 0;
		}
		
		// Set both output pins according to the current phase
		if (mouseEncoderPhaseX == 0 || mouseEncoderPhaseX == 1) X1_PORT |= X1;	// Set X1 to 1
		else X1_PORT &= ~X1;	// Set X1 to 0
		if (mouseEncoderPhaseX == 1 || mouseEncoderPhaseX == 2) X2_PORT |= X2;	// Set X2 to 1
		else X2_PORT &= ~X2;	// Set X2 to 0
		
		// Decrement the distance left to move
		mouseDistanceX--;
	}
	
	// Set the timer top value for the next interrupt, or stop the interrupt if there is
	// nothing left to output
	if (mouseDistanceX > 0) OCR1A = xTimerTop;
	else TIMSK1 &= ~(1 << OCIE1A);
}

// Interrupt Service Routine based on Timer3 for mouse Y movement quadrature output
ISR(TIMER3_COMPA_vect)
{
	// Process Y output
	if (mouseDistanceY > 0) {
		// Change phase and range check
		if (mouseDirectionY == 0) {
			mouseEncoderPhaseY--;
			if (mouseEncoderPhaseY < 0) mouseEncoderPhaseY = 3;
			} else {
			mouseEncoderPhaseY++;
			if (mouseEncoderPhaseY > 3) mouseEncoderPhaseY = 0;
		}
				
		// Set both output pins according to the current phase
		if (mouseEncoderPhaseY == 1 || mouseEncoderPhaseY == 2) Y1_PORT |= Y1;	// Set Y1 to 1
		else Y1_PORT &= ~Y1;	// Set Y1 to 0
		if (mouseEncoderPhaseY == 0 || mouseEncoderPhaseY == 1) Y2_PORT |= Y2;	// Set Y2 to 1
		else Y2_PORT &= ~Y2;	// Set Y2 to 0

		// Decrement the distance left to move
		mouseDistanceY--;
	}
	
	// Set the timer top value for the next interrupt, or stop the interrupt if there is
	// nothing left to output
	if (mouseDistanceY > 0) OCR3A = yTimerTop;
	else TIMSK3 &= ~(1 << OCIE3A);
}

// Main function
int main(void)
{
	// Initialise the SmallyMouse2 hardware
	initialiseHardware();
	
	// Initialise the ISR timers
	initialiseTimers();

	// Enable interrupts (required for USB support and quadrature output ISRs)
	sei();
	
	// Main processing loop
	while(1) {
		// Perform any pending mouse actions
		processMouse();

		// Process the USB host interface
		USB_USBTask();
	}
}

// Initialise the SmallyMouse2 hardware
void initialiseHardware(void)
{
	// Disable the watchdog timer (if set in fuses)
	MCUSR &= ~(1 << WDRF);
	wdt_disable();

	// Disable the clock divider (if set in fuses)
	clock_prescale_set(clock_div_1);

	// Set the quadrature output pins to output
	X1_DDR |= X1; // Output
	X2_DDR |= X2; // Output
	Y1_DDR |= Y1; // Output
	Y2_DDR |= Y2; // Output
	
	// Set quadrature output pins to zero
	X1_PORT &= ~X1; // Pin = 0
	X2_PORT &= ~X2; // Pin = 0
	Y1_PORT &= ~Y1; // Pin = 0
	Y2_PORT &= ~Y2; // Pin = 0
	
	// Set mouse button output pins open drain
	// (solves issues with some retro machines that
	// don't like 5V to be sources from the pins)
	LB_DDR &= ~LB; // 0 = input
	MB_DDR &= ~MB; // 0 = input
	RB_DDR &= ~RB; // 0 = input
	LB_PORT &= ~LB; // Pin = 0 (off)
	MB_PORT &= ~MB; // Pin = 0 (off)
	RB_PORT &= ~RB; // Pin = 0 (off)

	// Set the rate limit configuration header to input
	RATESW_DDR &= ~RATESW; // Input
	RATESW_PORT |= RATESW; // Turn on weak pull-up
	
	// Configure E7 on the expansion header to act as
	// DPISW (since it is easily jumpered to 0V)	
	DPISW_DDR &= ~DPISW; // Input
	DPISW_PORT |= DPISW; // Turn on weak pull-up
	
	// Initialise the expansion (Ian) header
	E0_DDR |= E0; // Output
	E1_DDR |= E1; // Output
	E2_DDR |= E2; // Output
	E3_DDR |= E3; // Output
	E4_DDR |= E4; // Output
	E5_DDR |= E5; // Output
	E6_DDR |= E6; // Output
	
	E0_PORT &= ~E0; // Pin = 0
	E1_PORT &= ~E1; // Pin = 0
	E2_PORT &= ~E2; // Pin = 0
	E3_PORT &= ~E3; // Pin = 0
	E4_PORT &= ~E4; // Pin = 0
	E5_PORT &= ~E5; // Pin = 0
	E6_PORT &= ~E6; // Pin = 0
	
	// Initialise the LUFA USB stack
	USB_Init();
	
	// By default, SmallyMouse2 will output USB debug events on the 
	// AVR's UART port.  You can monitor the debug console by connecting
	// a serial to USB adapter.  Only the Tx (D3 and 0V pins are required).
	
	// Initialise the interrupt driven serial UART - 9600 baud 8N1 - and
	// direct stdout to it
	// Note: The serial UART is available on the
	// expansion (Ian) header
	serialInit(9600);

	// Output some debug header information to the serial console
	puts_P(PSTR(ESC_FG_YELLOW "SmallyMouse2 V1.4 - Serial debug console\r\n" ESC_FG_WHITE));
	puts_P(PSTR(ESC_FG_YELLOW "(c)2017-2026 Simon Inns\r\n" ESC_FG_WHITE));
	puts_P(PSTR(ESC_FG_YELLOW "http://www.waitingforfriday.com\r\n" ESC_FG_WHITE));
	
	// Now report the status of the various configuration switches
	if ((RATESW_PIN & RATESW) == 0) puts_P(PSTR("Rate limit switch is ON\r\n"));
	else puts_P(PSTR("Rate limit switch is OFF\r\n"));
	if ((DPISW_PIN & DPISW) == 0) puts_P(PSTR("DPI divide switch is ON\r\n"));
	else puts_P(PSTR("DPI divide switch is OFF\r\n"));
}

// Initialise the ISR timers
void initialiseTimers(void)
{
	// The frequency of the reports from the USB mouse is about 100-125 Hz (i.e.
	// 100-125 reports per second).  Each report can indicate up to 127 position
	// movements in each direction (X & Y)
	
	// If we can receive 127 movements per report at a rate of 125 Hz
	// then the maximum movement per second is 100-125 Hz * 127 movements =
	// 12,700 - 15,875 movements per second (i.e. the quadrature output has 
	// to be 12,700 - 15,875 Hz to keep up)
	
	// The setting of the timers controls the maximum interrupt speed and 
	// therefore the maximum possible quadrature rate output.
	// 
	// Each movement unit reported by the USB device causes a single phase
	// change in the quadrature output (which means there is a 4:1 ratio
	// between the USB movement units and the quadrature movement output)
	
	// Timer1 and Timer3 are 16-bit timers in CTC mode, so each interrupt
	// period is (TOP + 1) ticks with a TOP of 0-65535.
	
	// Timer prescale is /8 and the AVR clock speed is 16,000,000 Hz
	// 16,000,000 Hz / 8 prescale = 2,000,000 ticks per second
	//
	// 1,000,000 uS per second / 2,000,000 ticks per second = 0.5 uS per tick
	//
	// The fine tick allows the output rate to closely follow the buffered
	// movement.  The fastest output is limited to Q_MAXRATE by
	// processMouseMovement() and the slowest possible is 32.768 mS per edge.

	// Configure Timer1 to interrupt (16-bit timer)
	OCR1A = Q_MAXRATE_TICKS - 1; // In CTC mode OCR1A = TOP
	TCCR1A = 0;
	TCCR1B = (1 << WGM12) | (1 << CS11); // Clear timer on compare match (CTC) mode, /8 prescale
	TIMSK1 = 0; // Timer1 interrupt disabled (started when there is movement to output)
		
	// Configure Timer3 to interrupt (16-bit timer)
	OCR3A = Q_MAXRATE_TICKS - 1; // In CTC mode OCR3A = TOP
	TCCR3A = 0;
	TCCR3B = (1 << WGM32) | (1 << CS31); // Clear timer on compare match (CTC) mode, /8 prescale
	TIMSK3 = 0; // Timer3 interrupt disabled (started when there is movement to output)
}
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

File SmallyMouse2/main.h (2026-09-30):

/*
 * SPDX-License-Identifier: GPL-3.0-or-later
 * SPDX-FileCopyrightText: 2017-2026 Simon Inns <simon.inns@gmail.com>
 *
 * main.h - Main functions
 * SmallyMouse2 - USB to quadrature mouse converter
 */

#ifndef _MAIN_H_
#define _MAIN_H_

// Hardware map

// Quadrature mouse output port
// Right mouse button
#define RB_PORT	PORTC
#define RB_PIN	PINC
#define RB_DDR	DDRC
#define RB		(1 << 6)

// Middle mouse button
#define MB_PORT	PORTC
#define MB_PIN	PINC
#define MB_DDR	DDRC
#define MB		(1 << 5)

// Left mouse button
#define LB_PORT	PORTC
#define LB_PIN	PINC
#define LB_DDR	DDRC
#define LB		(1 << 4)

// Y axis output
#define Y2_PORT	PORTC
#define Y2_PIN	PINC
#define Y2_DDR	DDRC
#define Y2		(1 << 3)

#define Y1_PORT	PORTC
#define Y1_PIN	PINC
#define Y1_DDR	DDRC
#define Y1		(1 << 1)

// X axis output
#define X2_PORT	PORTC
#define X2_PIN	PINC
#define X2_DDR	DDRC
#define X2		(1 << 2)

#define X1_PORT	PORTC
#define X1_PIN	PINC
#define X1_DDR	DDRC
#define X1		(1 << 0)

// Rate limit on/off switch (marked 'slow')
#define RATESW_PORT	PORTA
#define RATESW_PIN	PINA
#define RATESW_DDR	DDRA
#define RATESW		(1 << 4)

// Expansion (Ian) header
#define E0_PORT	PORTD
#define E0_PIN	PIND
#define E0_DDR	DDRD
#define E0		(1 << 0)

#define E1_PORT	PORTD
#define E1_PIN	PIND
#define E1_DDR	DDRD
#define E1		(1 << 1)

#define E2_PORT	PORTD
#define E2_PIN	PIND
#define E2_DDR	DDRD
#define E2		(1 << 2)

#define E3_PORT	PORTD
#define E3_PIN	PIND
#define E3_DDR	DDRD
#define E3		(1 << 3)

#define E4_PORT	PORTD
#define E4_PIN	PIND
#define E4_DDR	DDRD
#define E4		(1 << 4)

#define E5_PORT	PORTD
#define E5_PIN	PIND
#define E5_DDR	DDRD
#define E5		(1 << 5)

#define E6_PORT	PORTD
#define E6_PIN	PIND
#define E6_DDR	DDRD
#define E6		(1 << 6)


// E7 is now used as the DPISW header
#define DPISW_PORT	PORTD
#define DPISW_PIN	PIND
#define DPISW_DDR	DDRD
#define DPISW		(1 << 7)

// Function prototypes
void initialiseHardware(void);
void initialiseTimers(void);
void processMouse(void);
uint8_t mapButtons(uint8_t buttons);
void setButtonMapping(uint16_t vendorId, uint16_t productId);
void reportButtons(uint8_t buttons);
void startQuadratureTimers(void);
uint16_t processMouseMovement(int8_t movementUnits, uint8_t axis, bool limitRate, bool dpiDivide);

// USB callback event handlers (LUFA)
void EVENT_USB_Host_HostError(const uint8_t ErrorCode);
void EVENT_USB_Host_DeviceAttached(void);
void EVENT_USB_Host_DeviceUnattached(void);
void EVENT_USB_Host_DeviceEnumerationFailed(const uint8_t ErrorCode, const uint8_t SubErrorCode);
void EVENT_USB_Host_DeviceEnumerationComplete(void);

void ReadNextReport(void);

#endif

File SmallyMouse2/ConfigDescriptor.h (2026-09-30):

/*
             LUFA Library
     Copyright (C) Dean Camera, 2015.

  dean [at] fourwalledcubicle [dot] com
           www.lufa-lib.org
*/

/*
  Copyright 2015  Dean Camera (dean [at] fourwalledcubicle [dot] com)

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
  The author disclaims all warranties with regard to this
  software, including all implied warranties of merchantability
  and fitness.  In no event shall the author be liable for any
  special, indirect or consequential damages or any damages
  whatsoever resulting from loss of use, data or profits, whether
  in an action of contract, negligence or other tortious action,
  arising out of or in connection with the use or performance of
  this software.
*/

/** \file
 *
 *  Header file for ConfigDescriptor.c.
 */

#ifndef _CONFIGDESCRIPTOR_H_
#define _CONFIGDESCRIPTOR_H_

	/* Includes: */
		#include <LUFA/Drivers/USB/USB.h>

		#include "main.h"

	/* Macros: */
		/** Pipe address for the mouse data IN pipe. */
		#define MOUSE_DATA_IN_PIPE          (PIPE_DIR_IN | 1)

	/* Enums: */
		/** Enum for the possible return codes of the \ref ProcessConfigurationDescriptor() function. */
		enum MouseHost_GetConfigDescriptorDataCodes_t
		{
			SuccessfulConfigRead            = 0, /**< Configuration Descriptor was processed successfully */
			ControlError                    = 1, /**< A control request to the device failed to complete successfully */
			DescriptorTooLarge              = 2, /**< The device's Configuration Descriptor is too large to process */
			InvalidConfigDataReturned       = 3, /**< The device returned an invalid Configuration Descriptor */
			NoCompatibleInterfaceFound      = 4, /**< A compatible interface with the required endpoints was not found */
		};

	/* External Variables: */
		extern uint8_t MouseInterfaceNumber;

	/* Function Prototypes: */
		uint8_t ProcessConfigurationDescriptor(void);

		uint8_t DComp_NextMouseInterface(void* CurrentDescriptor);
		uint8_t DComp_NextMouseInterfaceDataEndpoint(void* CurrentDescriptor);

#endif

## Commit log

2026-09-17 Migrate KiCad project from KiCad 4.0.6 to KiCad 10
    Convert the hardware design to native KiCad 10 formats and make the
    schematic and board consistent with each other.
    Format migration
    - SmallyMouse2.kicad_sch: converted from legacy .sch; symbols rescued
    from the project cache into SmallyMouse2-rescue.kicad_sym
    - SmallyMouse2.kicad_pcb: upgraded; zones refilled with the KiCad 10
    filler (legacy fills undercut their own clearance)
    - SmallyMouse2.kicad_pro: reconstructed from the legacy board's
    net_class/setup section, which the new format keeps in the project
    file (Default netclass 0.2/0.25/0.6-0.4, min track 0.2, via 0.4/0.3)
    - SmallyMouse2.pretty: footprints exported from the board s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
    [SmallyMouse2.kicad_pcb, SmallyMouse2.kicad_sch, SmallyMouse2.sch]
2026-09-17 Sync PCB with schematic and finish test-point/junction cleanup
    Run Update PCB from Schematic in KiCad 10 so the board carries the
    schematic's net names (KiCad 4 auto-names such as Net-(IC1-Pad20)
    become Net-(IC1-~{RESET})) plus the pin function/type, sheet and unit
    metadata KiCad now stores per footprint. Schematic parity is clean.
    - J3 pins 1/19: split the crossing wires at the junctions so the
    editor keeps them (a bare junction on unbroken wires is discarded on
    load); +5V/GND now reach the pads from the schematic side as well
    - Test points: KiCad requires numbered references, so return to
    TP1-TP7 in the schematic; on the board hide the reference and show
    the value (RST, TMS, TDI,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
    [SmallyMouse2.kicad_pcb, SmallyMouse2.kicad_sch]
2026-09-17 Fix starved thermal reliefs on J3 GND pads 7, 15 and 17
    The even-pin signal tracks run to the right exactly between J3's GND
    pads and the signal column is too close for the pour to fill, so these
    three pads could only get one thermal spoke (KiCad 10 requires two).
    Add a short GND track from each pad into the pour, as the original
    layout already does for pads 5 and 19, and refill the zones.
    DRC is now clean apart from two silkscreen-clipped-by-edge warnings.
    [SmallyMouse2.kicad_pcb]
2026-09-17 README: note that the KiCad project now requires KiCad 10
2026-09-29 Add a note to the schematic about the debug UART Tx and update the schematic page text
    [SmallyMouse2.kicad_sch]
2026-09-30 Remove the local copy of LUFA and pin it via nix instead
2026-09-30 Fix some bugs, improve the ISR and rewrite the DPU divider
    [main.c]
2026-09-30 Improve the SLOW handling to prevent stalling on quick movement
    [main.c]
2026-09-30 Make the UART interrupt driven - add button remapping for Kensington Expert mice (for Domesday use)
2026-09-30 Add an OpenSCAD case project - update KiCAD board to include 3D model rendering
    [SmallyMouse2.kicad_pcb, case.scad, pcb.scad]
2026-09-30 Include case design in OpenSCAD
    [case.scad, pcb.scad]
2026-09-30 Correct the lid clearance for a case with only the IDC
    [case.scad]
2026-10-19 Remove the custom USB VID/PID button swap and use two firmware images instead

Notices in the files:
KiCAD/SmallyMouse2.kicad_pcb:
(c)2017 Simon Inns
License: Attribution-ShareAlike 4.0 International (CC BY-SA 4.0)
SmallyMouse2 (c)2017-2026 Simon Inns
